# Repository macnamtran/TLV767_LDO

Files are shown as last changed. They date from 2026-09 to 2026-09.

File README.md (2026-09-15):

# TLV767 5 V-to-3.3 V LDO Power Supply PCB

## 1. Project Overview

A KiCad power-supply board designed to convert a **5 V DC input to a nominal 3.3 V output** using the adjustable **TLV76701DRVx** linear regulator with fixed feedback resistors.

The project covers datasheet-based component selection, feedback calculations, schematic capture, PCB layout, electrical/design-rule checking, and PSpice startup/load-transient evaluation.

**Status:** Schematic and PCB layout prepared; ERC and DRC reports are included. Nominal startup and load-transient simulations are complete; fabrication and bench testing are pending. Output current capability has not yet been established for this board.

This revision replaces the earlier potentiometer-adjustable design. Earlier files remain available in Git history.

### Schematic

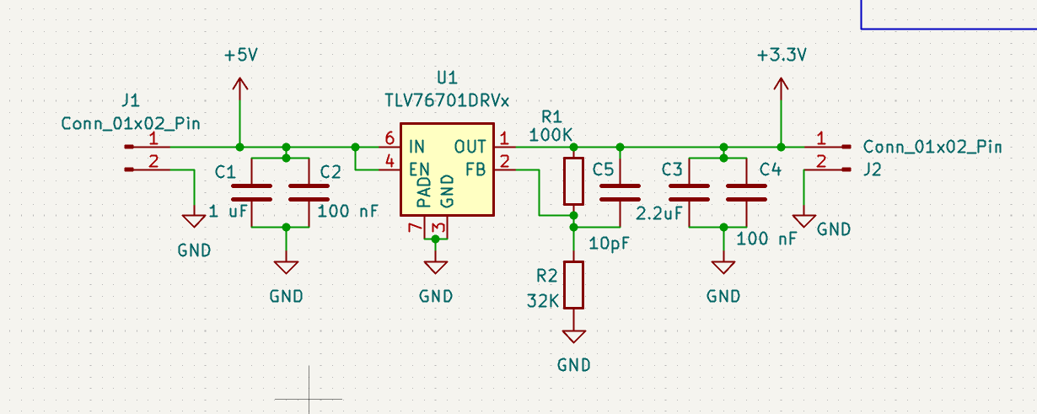
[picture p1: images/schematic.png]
TLV767 5 V-to-3.3 V schematic


### PCB Layout

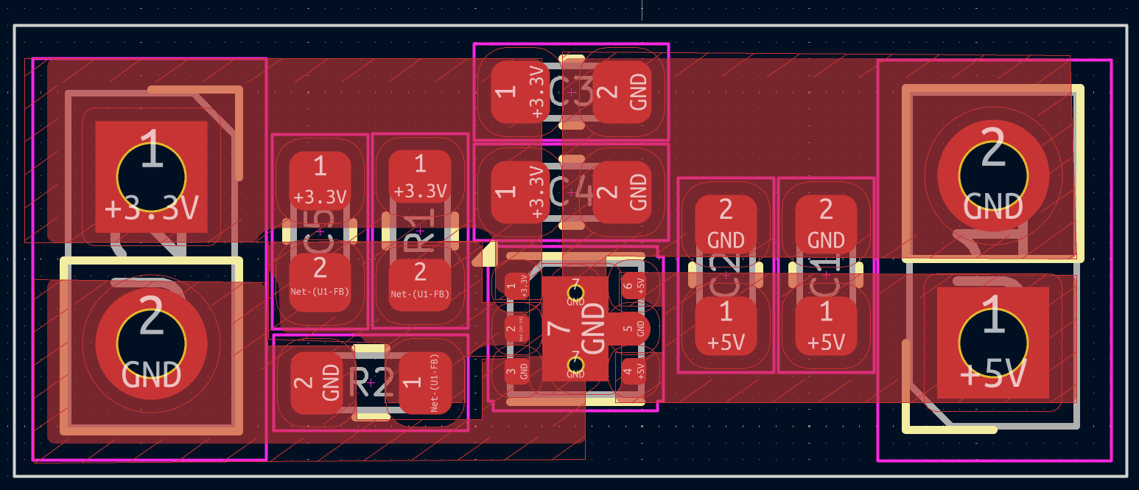
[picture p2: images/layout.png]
TLV767 PCB layout


### 3D View

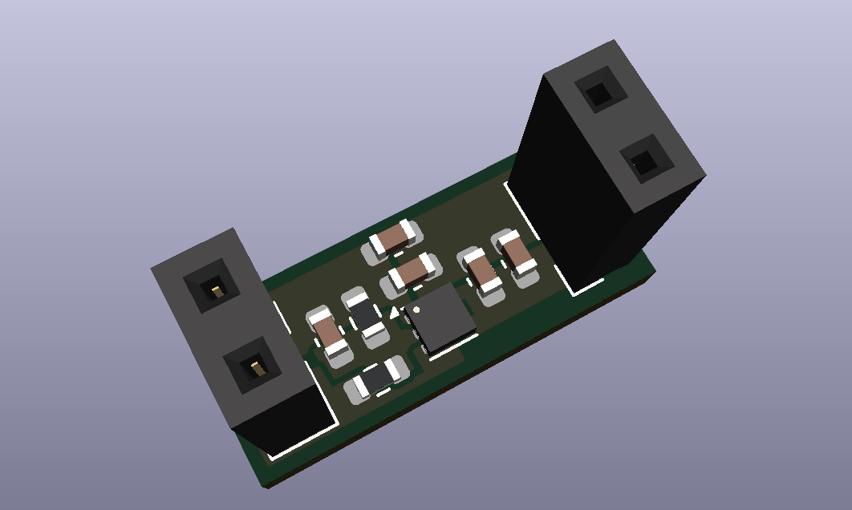
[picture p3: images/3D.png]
TLV767 PCB 3D rendering — not a fabricated board


## 2. Design Targets

| Parameter | Current design |
|---|---|
| Input voltage | 5 V DC |
| Nominal output voltage | 3.3 V, set by fixed resistors |
| Regulator | TLV76701DRVx |
| Package | DRV, 6-pin WSON, 2 mm × 2 mm, exposed pad |
| EDA tool | KiCad 9 |
| Routing | Tracks and copper zones on F.Cu |
| Bottom copper | No routed tracks or ground plane; through-hole pads include bottom copper |
| Output current | Target to be defined and checked against thermal limits |
| Hardware validation | Not fabricated or bench-tested |

The PCB file enables F.Cu and B.Cu; this is described as **top-layer routing**, rather than a confirmed single-copper-layer fabrication stackup.

## 3. Datasheet Information Used

The [TI TLV767 datasheet](https://www.ti.com/lit/ds/symlink/tlv767.pdf) provides the reference voltage, capacitor requirements, pinout, and layout guidance used for this design.

- Nominal feedback reference: **0.8 V**.
- The adjustable device uses an external resistor divider to set its output.
- EN may be connected to IN for always-on operation.
- Both GND pins must be grounded.
- Capacitor selection must account for effective capacitance, ESR, voltage rating, tolerance, and DC-bias effects.

The regulator's advertised current capability is a device rating, not a verified current rating for this PCB.

## 4. Pin Connection Summary

| Pin | Function | Connection |
|---|---|---|
| 1 | OUT | +3.3 V output |
| 2 | FB | R1/R2 divider junction |
| 3, 5 | GND | Ground |
| 4 | EN | +5 V input |
| 6 | IN | +5 V input |
| 7 | Exposed pad | Ground |

Input power enters through J1; J2 provides the output. PWR_FLAG symbols identify the externally supplied +5 V and ground nets for ERC.

## 5. Component Choices

| Reference | Value | Role |
|---|---|---|
| U1 | TLV76701DRVx | Adjustable linear regulator |
| R1 | 100 kΩ | Upper feedback resistor, OUT to FB |
| R2 | 32 kΩ | Lower feedback resistor, FB to GND |
| C1 | 1 µF | Input capacitance |
| C2 | 100 nF | Additional input bypass |
| C3 | 2.2 µF | Output capacitance |
| C4 | 100 nF | Additional output bypass |
| C5 | 10 pF | Feed-forward capacitor across R1 |
| J1, J2 | Two-pin connectors | Input and output connections |

C5 is included in the simulated circuit; its individual effect has not been isolated with a with/without comparison. Final capacitor part numbers, effective capacitance, and resistor tolerances remain to be documented.

## 6. Design Calculations

### Nominal output voltage

Using the nominal reference and resistor values:

```text
VOUT = VFB × (1 + R1/R2)
     = 0.8 × (1 + 100 kΩ / 32 kΩ)
     = 3.3 V
```

This is a calculated nominal value. Reference accuracy, resistor tolerances, and operating conditions affect the actual output.

### Regulator dissipation

Ignoring quiescent current for this first-order estimate:

```text
PD ≈ (VIN − VOUT) × IOUT
   ≈ 1.7 × IOUT
```

| Example load | Calculated regulator dissipation |
|---|---|
| 100 mA | 0.17 W |
| 250 mA | 0.425 W |
| 500 mA | 0.85 W |
| 1 A | 1.7 W |

These are illustrative calculations, not approved operating points. Board copper, ambient temperature, assembly, and package thermal behaviour must be considered before selecting a continuous-current rating.

## 7. PCB Layout Considerations

- Input capacitors are placed beside the regulator input.
- Output capacitors and the feedback network are placed near U1.
- Top-layer copper zones carry +5 V, +3.3 V, ground, and the feedback net.
- The U1 footprint includes two plated holes in its grounded exposed-pad area.
- There is no bottom ground plane; no measured heat-spreading benefit is claimed.
- U1 differs from the installed library footprint only in front-silkscreen graphics, as reviewed using KiCad's footprint comparison.

Manufacturing review should include the exposed-pad holes, solder-paste arrangement, and the selected board manufacturer's capabilities.

## 8. Verification and Limitations

Checks recorded on September 14, 2026:

| Check | Result |
|---|---|
| Schematic ERC | 0 errors, 0 warnings under configured checks |
| PCB DRC | 0 errors, 1 library-footprint warning |
| Unconnected pads | 0 |
| PCB–schematic parity | 0 issues in the parity-enabled DRC run |
| Footprint warning review | Front-silkscreen-only differences |
| Startup and load-transient simulation | Completed; see results below |
| Fabrication / bench testing | Pending |

Reports: [ERC](docs/ERC-report.rpt) · [DRC](docs/DRC-report.rpt)

Four ERC check categories and five DRC check categories were ignored in the recorded configuration. These results do not represent all checks being enabled.

The ignored DRC categories were:
- Footprint has no courtyard defined.
- Footprint does not match the symbol's footprint filters.
- PTH inside courtyard.
- NPTH inside courtyard.
- Footprint component type does not match footprint pads.

The four ignored ERC categories still need to be recorded and reviewed. No manufacturer DFM approval, bench-verified electrical performance, or thermal validation is claimed.

### PSpice simulation results

Nominal tests use a 5 V input and TI's TLV76701 transient model. Saved profiles and run logs were reviewed on September 15, 2026; both logs report completion without simulation errors.

| Test | Conditions | Approximate result |
|---|---|---|
| Startup | 33 Ω load (~100 mA), 3 ms run, 20 ns maximum timestep | 0.42 ms rise time between manually selected points near 10% and 90% of nominal output |
| Load application | ~10 to 100 mA, 1 µs edge | 10.6 mV output dip relative to pre-step voltage |
| Load removal | ~100 to 10 mA, 1 µs edge | 11.0 mV overshoot relative to pre-step voltage |

The load-transient test runs for 5 ms with a 100 ns maximum timestep. These are rounded cursor readings from schematic-level simulations, not PCB measurements. The startup rise time excludes startup delay. Ideal external capacitors do not include ESR, DC-bias derating or PCB parasitics.

[Simulation settings, reproduction instructions and limitations](simulation/README.md)

- [Startup waveform](simulation/startup_33ohm/startup_5V_3V3_33ohm.png)
- [Startup rise-time cursors](simulation/startup_33ohm/startup_rise_time_33ohm.png)
- [Load-transient overview](simulation/load_transient_10mA_100mA/load_transient_overview.png)
- [Output dip](simulation/load_transient_10mA_100mA/load_step_10to100mA_dip.png)
- [Output overshoot](simulation/load_transient_10mA_100mA/load_step_100to10mA_overshoot.png)

## 9. Repository Contents

| Path | Contents |
|---|---|
| [TLV767_LDO.kicad_pro](TLV767_LDO.kicad_pro) | KiCad project settings |
| [TLV767_LDO.kicad_sch](TLV767_LDO.kicad_sch) | Editable schematic |
| [TLV767_LDO.kicad_pcb](TLV767_LDO.kicad_pcb) | Editable PCB layout |
| [images/](images/) | Schematic, layout, and 3D views |
| [docs/](docs/) | ERC and DRC reports |
| [simulation/](simulation/) | PSpice projects, profiles, netlists, logs and result screenshots |

## 10. Next Steps

1. Define the intended load and continuous-current target.
2. Complete component-tolerance, thermal, and manufacturing review.
3. Review ignored rule checks and document their settings.
4. Extend simulation to input transients and component variations.
5. Fabricate and perform bench tests when equipment and budget allow.

## References

- [TI TLV767 product page and simulation models](https://www.ti.com/product/TLV767)
- [TLV767 datasheet](https://www.ti.com/lit/ds/symlink/tlv767.pdf)
- [PSpice for TI](https://www.ti.com/tool/PSPICE-FOR-TI)

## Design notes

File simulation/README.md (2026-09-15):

# TLV76701 simulation review

Reviewed from the supplied PSpice project archives on 2026-09-15. This is a file and saved-result review; the simulations were not rerun here. Original circuit, model and result bytes are preserved. Backup files, lock/cache files and duplicate startup screenshots in the load-transient case were omitted.

## Verified saved settings

| Setting | Startup | Load transient |
| --- | --- | --- |
| Input | 0 to 5 V at 200 us; 1 us rise/fall | Same |
| Input pulse width / period | 4 ms / 2 s | 10 ms / 2 s |
| Run time | 3 ms | 5 ms |
| Maximum timestep | 20 ns | 100 ns |
| Save data after | 0 | 0 |
| Skip initial bias point | Off | Off |
| Resistor load | 33 ohm (about 100 mA) | 330 ohm (about 10 mA) |
| Additional current sink | None | 0 to 90 mA; delay 2 ms; rise/fall 1 us; width 1 ms; period 10 ms |

Both generated netlists use the TLV76701_TRANS subcircuit with EN tied to VIN, a 100 kohm upper / 32 kohm lower feedback divider, 1 uF + 100 nF input capacitance, 2.2 uF + 100 nF output capacitance and 10 pF OUT-to-FB capacitance. The capacitor values and connections match the supplied schematic screenshot. The total external load is approximately 10 to 100 mA; plot I(RLOAD)+I(I1). I(RLOAD) alone remains near 10 mA.

Both saved output logs report JOB CONCLUDED, with no simulation error or convergence warning found. The model signature logs report Signature valid. The ordinary generated-file overwrite notice is not a simulation failure. All included PNGs decode successfully, including load_transient_schematic.png.

## Results recorded with the supplied cursor screenshots

| Quantity | Approximate result | Interpretation |
| --- | --- | --- |
| Startup rise time | 0.42 ms | Manually selected points near 10% and 90% of nominal 3.3 V; excludes startup delay |
| Load application dip | 10.6 mV | Relative to the output immediately before the roughly 10-to-100 mA step |
| Load removal overshoot | 11.0 mV | Relative to the output immediately before the roughly 100-to-10 mA step |

These are rounded cursor-based simulation readings, not newly computed global extrema or hardware measurements. The load returns near 3 ms (pulse fall starts at 3.001 ms). Recovery time was not quantified.

## Screenshot evidence

- [Startup overview](startup_33ohm/startup_5V_3V3_33ohm.png)
- [Startup rise-time cursors](startup_33ohm/startup_rise_time_33ohm.png)
- [Load-transient schematic](load_transient_10mA_100mA/load_transient_schematic.png)
- [Load-transient overview](load_transient_10mA_100mA/load_transient_overview.png)
- [Load application dip](load_transient_10mA_100mA/load_step_10to100mA_dip.png)
- [Load removal overshoot](load_transient_10mA_100mA/load_step_100to10mA_overshoot.png)

## Opening and reproducing

1. Download or clone this repository on a Windows computer with PSpice for TI, keeping each case folder intact.
2. Open TLV76701_TRANS.opj inside the desired case folder and select STARTUP-trans.
3. Check the saved settings against the table and run. Use V(VIN), V(OUT), I(RLOAD), and for the load-transient case I(RLOAD)+I(I1).
4. Plot settings and run logs are under TLV76701_TRANS-PSpiceFiles/STARTUP/trans/. The load-transient case includes trans.dat. The approximately 37 MB startup trans.dat is omitted from GitHub and retained in the original backup archive; rerun the startup profile to regenerate it in this directory.

The OPJ design, profile and local-model references are relative. The generated circuit references ../../../tlv76701_trans.lib. Standard nom_pspti.lib and nom.lib depend on the local PSpice installation. Historical absolute paths remain in GUI state and provenance comments; reopening on another computer has not been tested. Open PAGE1 through the project tree if a restored window points to the old location.

The schematic displays a legacy TPS74601P_TRANS label, but the actual generated netlist instantiates TLV76701_TRANS and the supplied model declares that subcircuit. Do not rename model symbols merely to change the displayed label.

## Scope and model attribution

This is nominal schematic-level startup and load-transient evidence. It does not establish PCB thermal performance, continuous current capability, production tolerances, noise, or full stability margins. Capacitor ESR, DC-bias derating and PCB parasitics are not represented by the ideal external components in these netlists.

The supplied encrypted model is Texas Instruments TLV76701P transient model, Final 1.00, dated 21DEC2018. Its original copyright and notices are retained. The header states noise and temperature effects are not modelled; it says quiescent/shutdown currents are modelled, whereas the example schematic note says quiescent current is not modelled. No quiescent-current conclusion is made here. Third-party model files remain subject to their original terms; this package assigns them no new license.

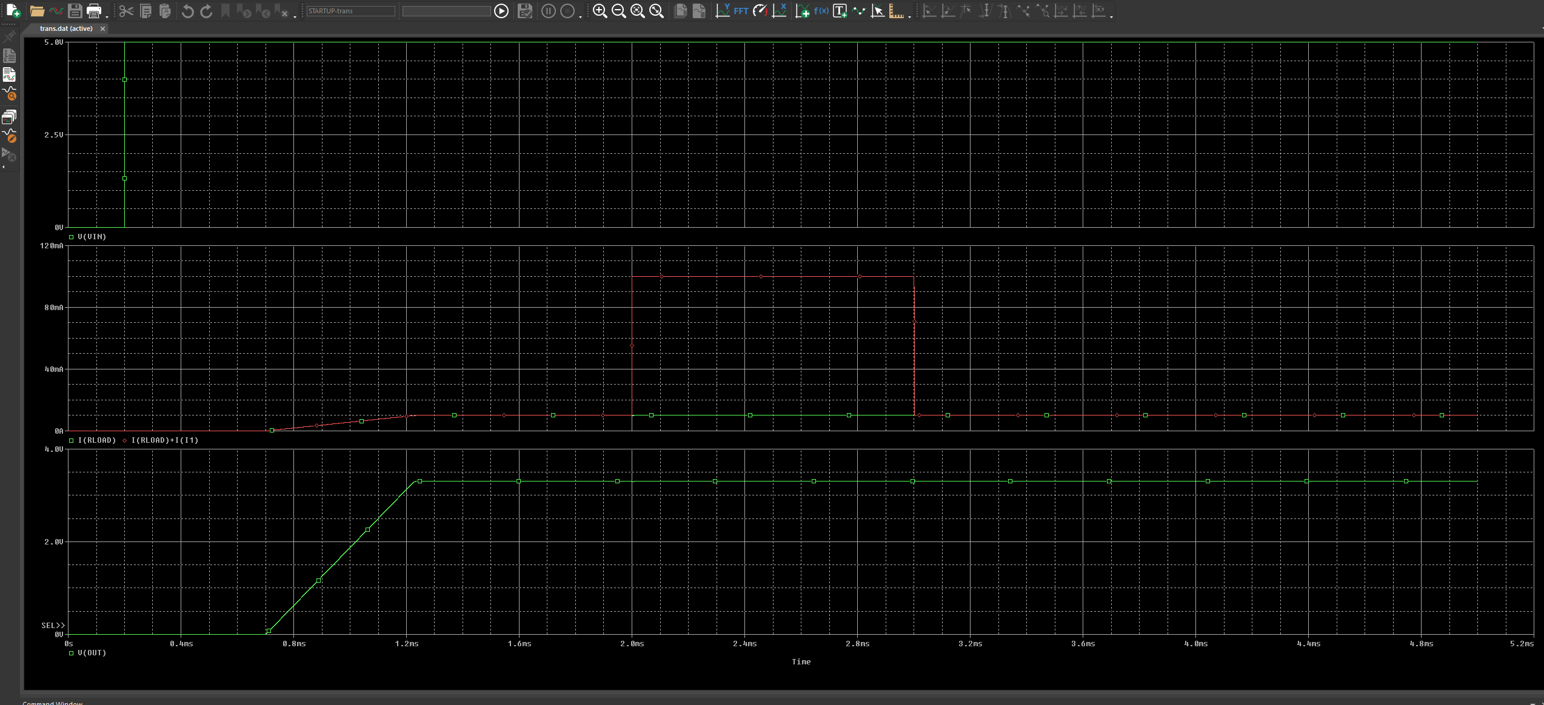
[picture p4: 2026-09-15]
simulation/load_transient_10mA_100mA/load_transient_overview.png

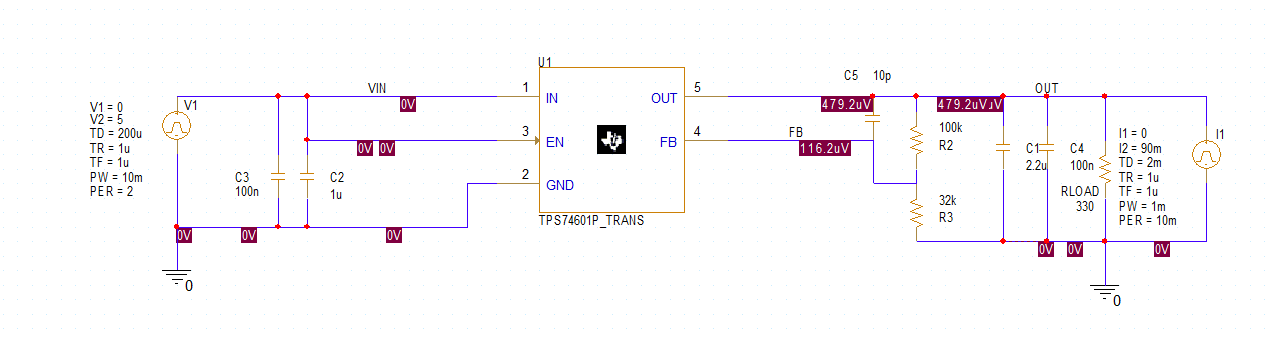
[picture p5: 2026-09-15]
simulation/load_transient_10mA_100mA/load_transient_schematic.png

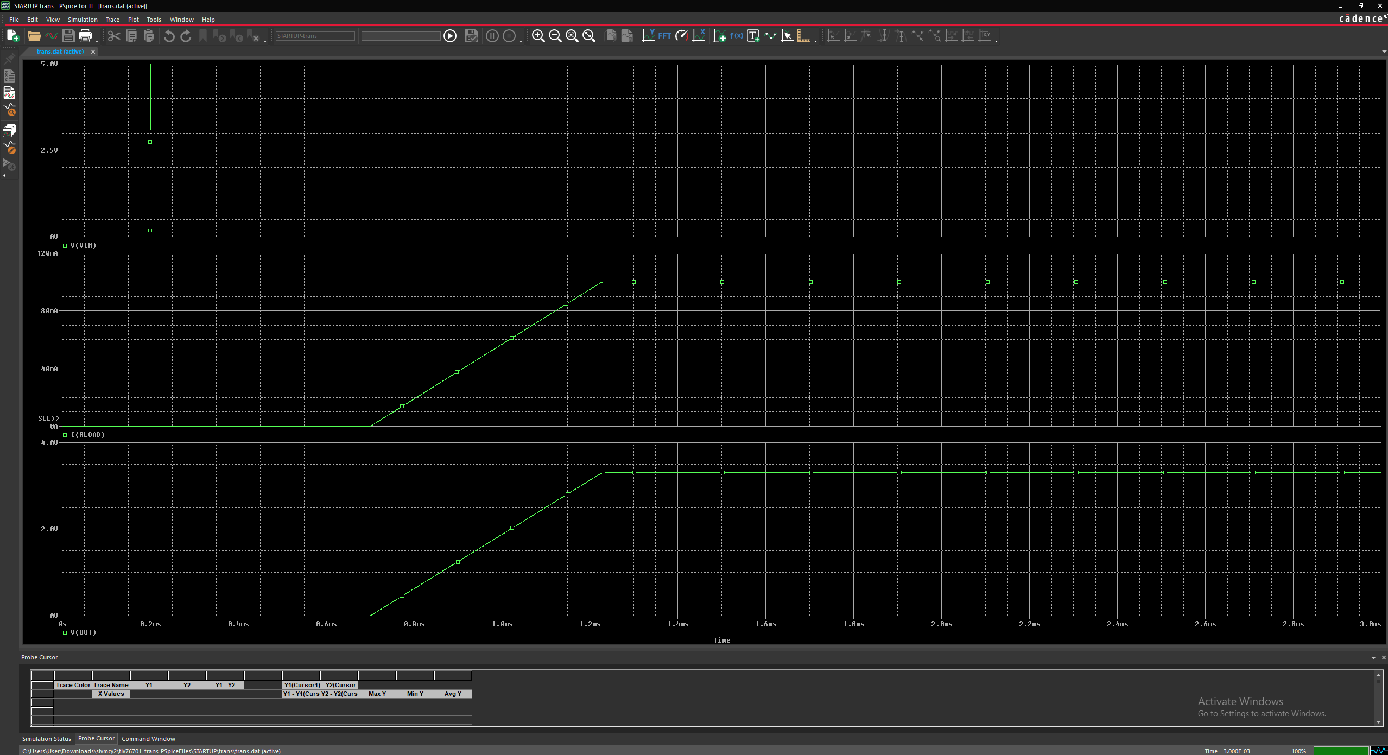
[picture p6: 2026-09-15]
simulation/startup_33ohm/startup_5V_3V3_33ohm.png

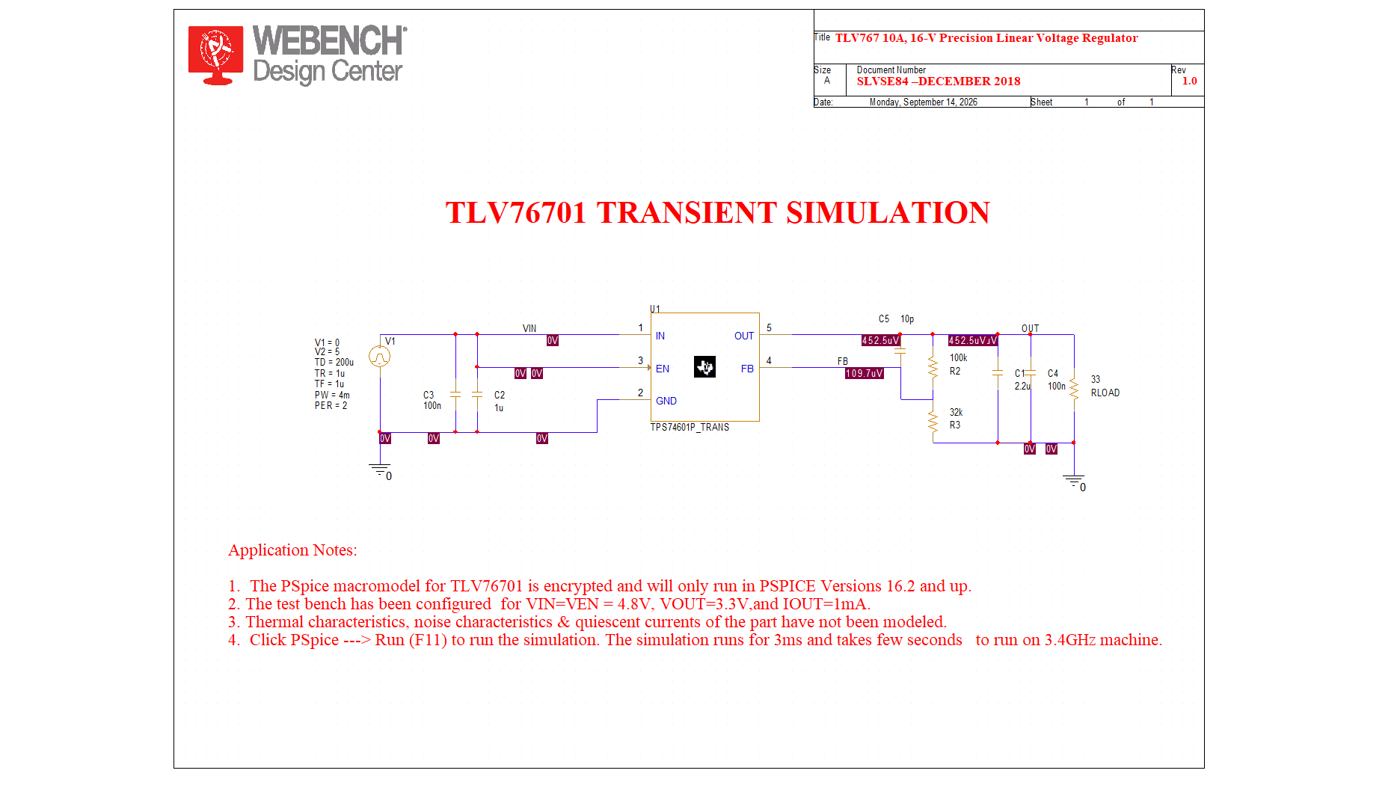
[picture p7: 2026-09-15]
simulation/startup_33ohm/TLV76701_TRANS.png

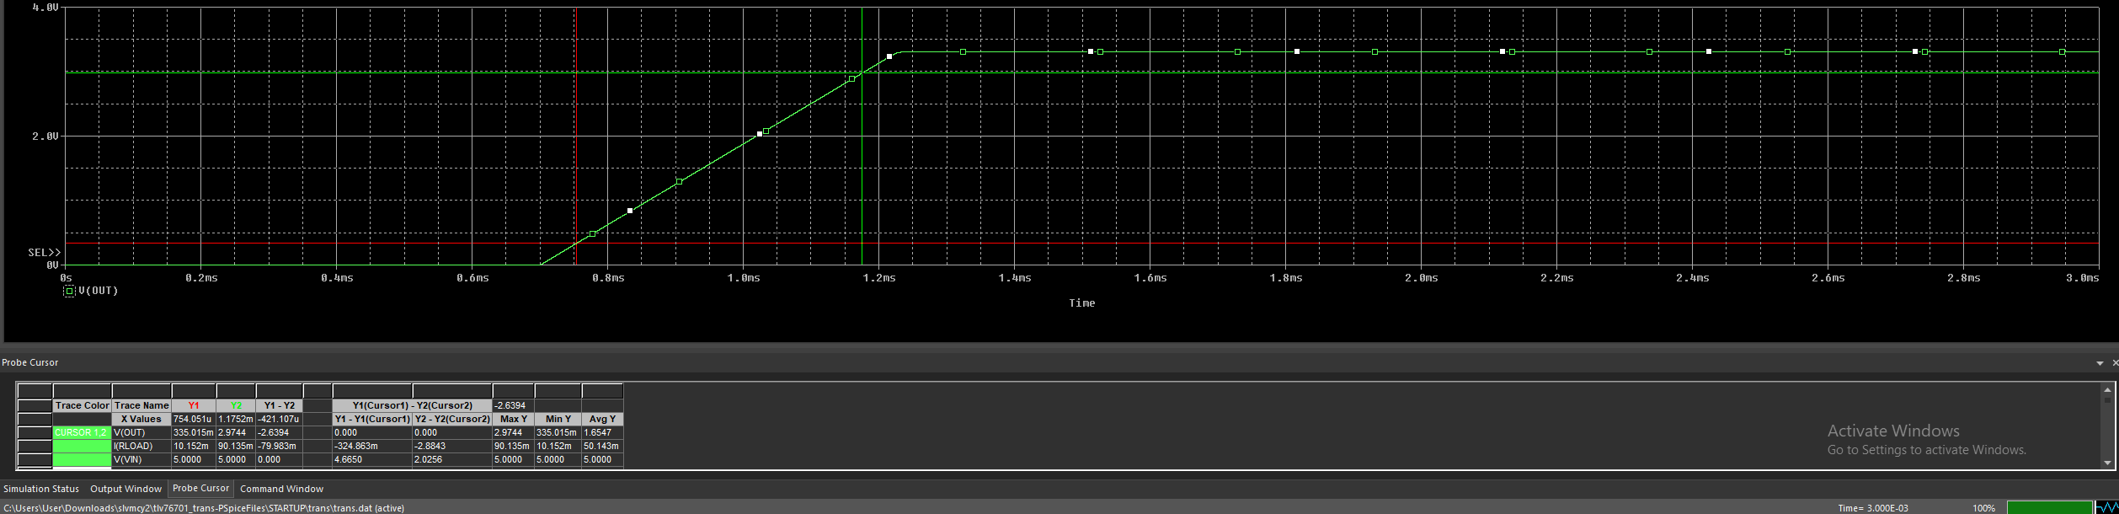
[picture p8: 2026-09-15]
simulation/startup_33ohm/startup_rise_time_33ohm.png

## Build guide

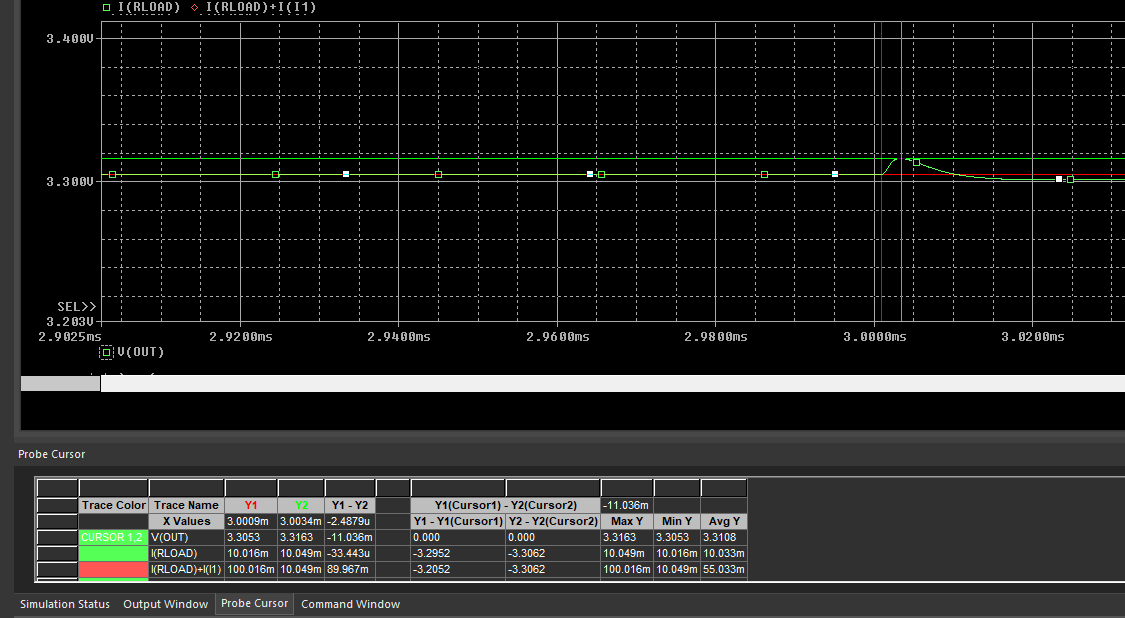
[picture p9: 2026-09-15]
simulation/load_transient_10mA_100mA/load_step_100to10mA_overshoot.png

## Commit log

2026-09-14 Update 5V-to-3.3V design and add ERC/DRC reports
    [TLV767_LDO.kicad_pcb, TLV767_LDO.kicad_sch]
2026-09-14 Update portfolio images for 5V-to-3.3V revision
2026-09-14 Document 5V-to-3.3V revision, calculations, and verification status
2026-09-15 Add startup and load-transient simulations
    [TLV76701_TRANS.DSN]
